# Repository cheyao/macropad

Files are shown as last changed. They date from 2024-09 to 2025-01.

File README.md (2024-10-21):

# Macropad
Hello! This is my first time designing a PCB and a CAD.

<p align="middle">
    
    
    
</p>

Designed using:

- KiCad - Made a ton of revisions
- OpenSCAD then FreeCAD (Fusion 360 doesn't work on my mac lol) Got like 400 constraints in my freecad project
- Python firmware

## Notes
Making the pad was fun ^.^ but I was just too paranoid that something would go wrong and made 15+ revisions lol. Ended up learning how to use OpenSCAD and FreeCAD.

## BOM
- 1 SEEEDUINO XIAO RP2040
- 16x [Kailh Choc V2 switches](https://www.kailh.net/products/kailh-choc-v2-low-profile-switch-set)
- 16x 1N4148 diodes
- 1x SSD1306 128x64O LED (5V VCC, 3.3V logic, I2C)
- 4x [SK6812-MINI-E LED](https://www.adafruit.com/product/4960)
- 2x 4.7k resistor
- 4x 0.1 uF capacitor (code 104, not obligatory but best have)
- 1x 1 uF capacitor (105 not obligatory)
- 4x same screws as orpheuspad and corresponding nuts
- 1kg of 99.99% gold please UwU

Interactive bom at `PCB/production/ibom.html`

## File list:

```
.
├── CAD                                         # 3D Files
│   ├── case.FCStd                              # Case FreeCAD design file
│   └── case
│       └── case.stl                            # The stl for the case
├── PCB
│   ├── macropad.step                           # 3D Model of the board
│   ├── production                              # The output directory for production (Just send this folder to JLCPCB)
│   │   ├── Cyao_macropad_v7.6.zip              # Final gerbers
│   │   ├── *.{csv,ipc}                         # Misc files for JLCPCB
│   │   └── ibom.html                           # Interactive bom for PCBAlex <3
│   └── third_party                             # 3rd party libraries
│       ├── Kalih                               # The keys
│       ├── OPL_Kicad_Library                   # Seed footprint
│       ├── KiCad-SSD1306-128x64-master         # LCD
│       └── Seeeduino-xiao-rp2040-KiCAD-Library # Seed schema
└── firmware                                    # Directory of my own firmware
    ├── adafruit-circuitpython-seeeduino_xiao_rp2040-en_US-9.1.4.uf2 # Circuitpython firmware
    ├── main.py                                 # Main firmware
    ├── boot.py                                 # Boot options (empty)
    └── kmk                                     # kmk firmware
```

NOTE: I will need a 0.96” SSD1306 OLED screen that accepts 5V with 3.3V logic

The resistors are allso probably optional - but suggested by reddit

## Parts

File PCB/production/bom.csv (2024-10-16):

Designator | Footprint | Quantity | Value | LCSC Part #
BRD1 | 128x64OLED | 1 | SSD1306
C1, C3, C4, C5 | C_Disc_D3.0mm_W1.6mm_P2.50mm | 4 | 0.1uF
C2 | C_Disc_D3.0mm_W1.6mm_P2.50mm | 1 | 1uF
D1, D10, D11, D12, D13, D14, D15, D16, D2, D3, D4, D5, D6, D7, D8, D9 | D_DO-35_SOD27_P7.62mm_Horizontal | 16 | Didode 1N4148
D17, D18, D21, D22 | SK6812MINI-E | 4 | SK6812MINI
R1, R2 | R_Axial_DIN0204_L3.6mm_D1.6mm_P7.62mm_Horizontal | 2 | 4.7k
SW1, SW10, SW11, SW12, SW13, SW14, SW15, SW16, SW2, SW3, SW4, SW5, SW6, SW7, SW8, SW9 | SW_Kailh_Choc_V2_1.00u | 16 | Kailh Choc V2
U2 | XIAO-Generic-Hybrid-14P-2.54-21X17.8MM | 1 | SEEEDUINO XIAO RP2040

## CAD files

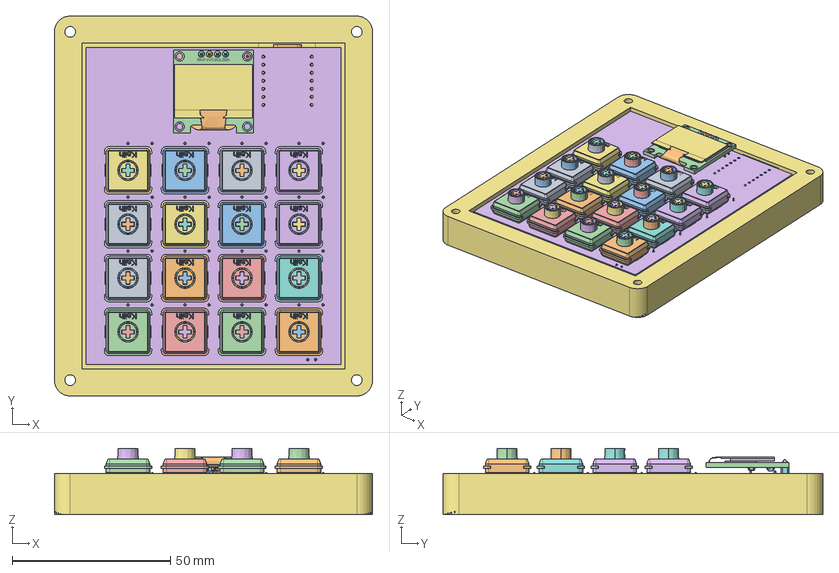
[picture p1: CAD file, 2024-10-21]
CAD/case.FCStd
100.5 x 120.0 x 21.0 mm
Kailh_PG1368
Kailh_PG1369
Kailh_PG1370
Kailh_PG1372
Kailh_PG1373
Kailh_PG1374
Kailh_PG1376
Kailh_PG1377
Kailh_PG1378
Kailh_PG1380
Kailh_PG1381
Kailh_PG1382
Kailh_PG1384
Kailh_PG1385
Kailh_PG1386
Kailh_PG1388
Kailh_PG1389
Kailh_PG1390
Kailh_PG1392
Kailh_PG1393
Kailh_PG1394
Kailh_PG1396
Kailh_PG1397
Kailh_PG1398
Kailh_PG1400
Kailh_PG1401
Kailh_PG1402
SSD1306_OLED_Display(128x64) v024
SSD1306_OLED_Display(128x64) v025
SSD1306_OLED_Display(128x64) v026
SSD1306_OLED_Display(128x64) v027
SSD1306_OLED_Display(128x64) v028
SSD1306_OLED_Display(128x64) v029
SSD1306_OLED_Display(128x64) v030
SSD1306_OLED_Display(128x64) v031
SSD1306_OLED_Display(128x64) v032
SSD1306_OLED_Display(128x64) v033
SSD1306_OLED_Display(128x64) v034
SSD1306_OLED_Display(128x64) v035
SSD1306_OLED_Display(128x64) v036
SSD1306_OLED_Display(128x64) v037
SSD1306_OLED_Display(128x64) v038
SSD1306_OLED_Display(128x64) v039
SSD1306_OLED_Display(128x64) v040
SSD1306_OLED_Display(128x64) v041
SSD1306_OLED_Display(128x64) v042
SSD1306_OLED_Display(128x64) v043
SSD1306_OLED_Display(128x64) v044
SSD1306_OLED_Display(128x64) v045
SSD1306_OLED_Display(128x64) v046
SSD1306_OLED_Display(128x64) v047
SSD1306_OLED_Display(128x64) v048
SSD1306_OLED_Display(128x64) v049
SSD1306_OLED_Display(128x64) v050
SSD1306_OLED_Display(128x64) v051
SSD1306_OLED_Display(128x64) v052
SSD1306_OLED_Display(128x64) v053
SSD1306_OLED_Display(128x64) v054
SSD1306_OLED_Display(128x64) v055
SSD1306_OLED_Display(128x64) v056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

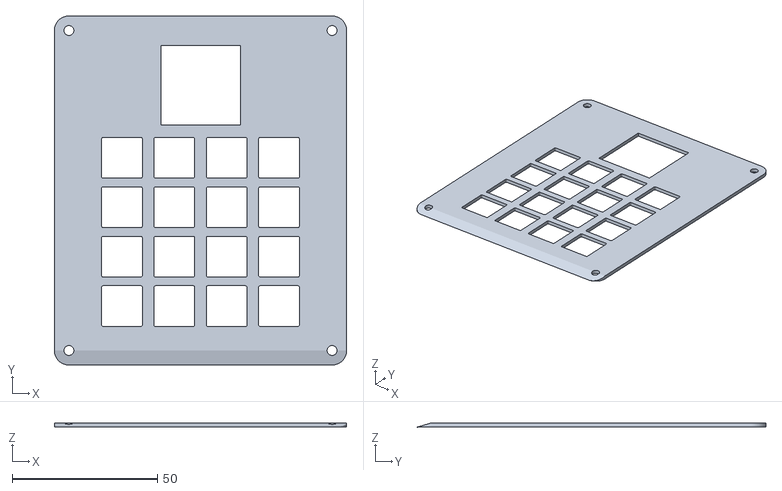
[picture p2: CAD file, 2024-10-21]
CAD/case/top.stl
100.5 x 120.0 x 1.50

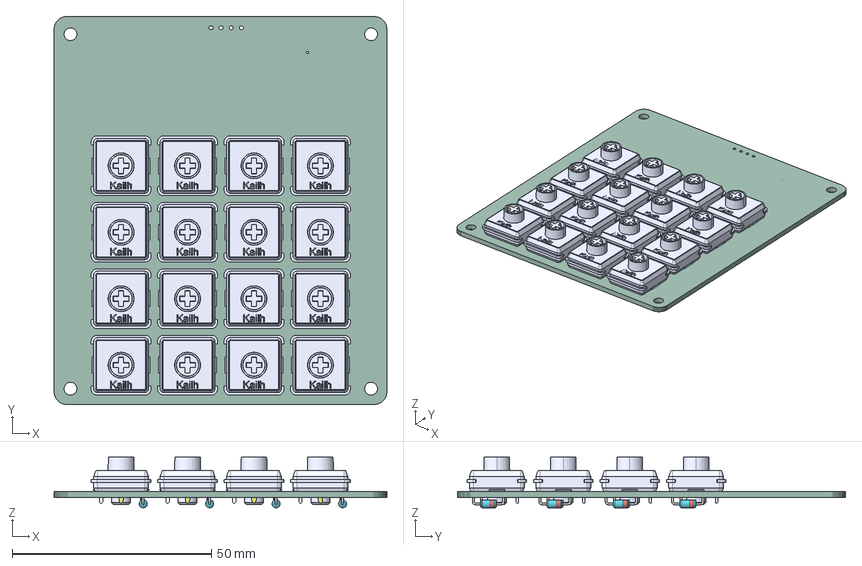
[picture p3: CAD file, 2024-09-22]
PCB/macropad.step
83.5 x 97.3 x 12.7 mm
Kailh_PG1352 x 16
D_DO-35_SOD27_P7.62mm_Horizontal x 16
macropad PCB

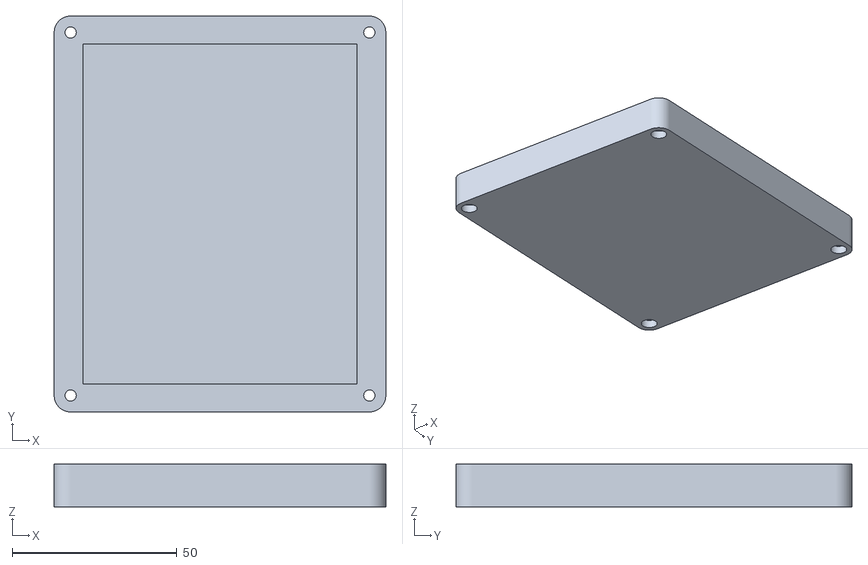
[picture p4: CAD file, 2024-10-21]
CAD/case/case.stl
100.5 x 120.0 x 13.0

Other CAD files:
CAD/case.stl

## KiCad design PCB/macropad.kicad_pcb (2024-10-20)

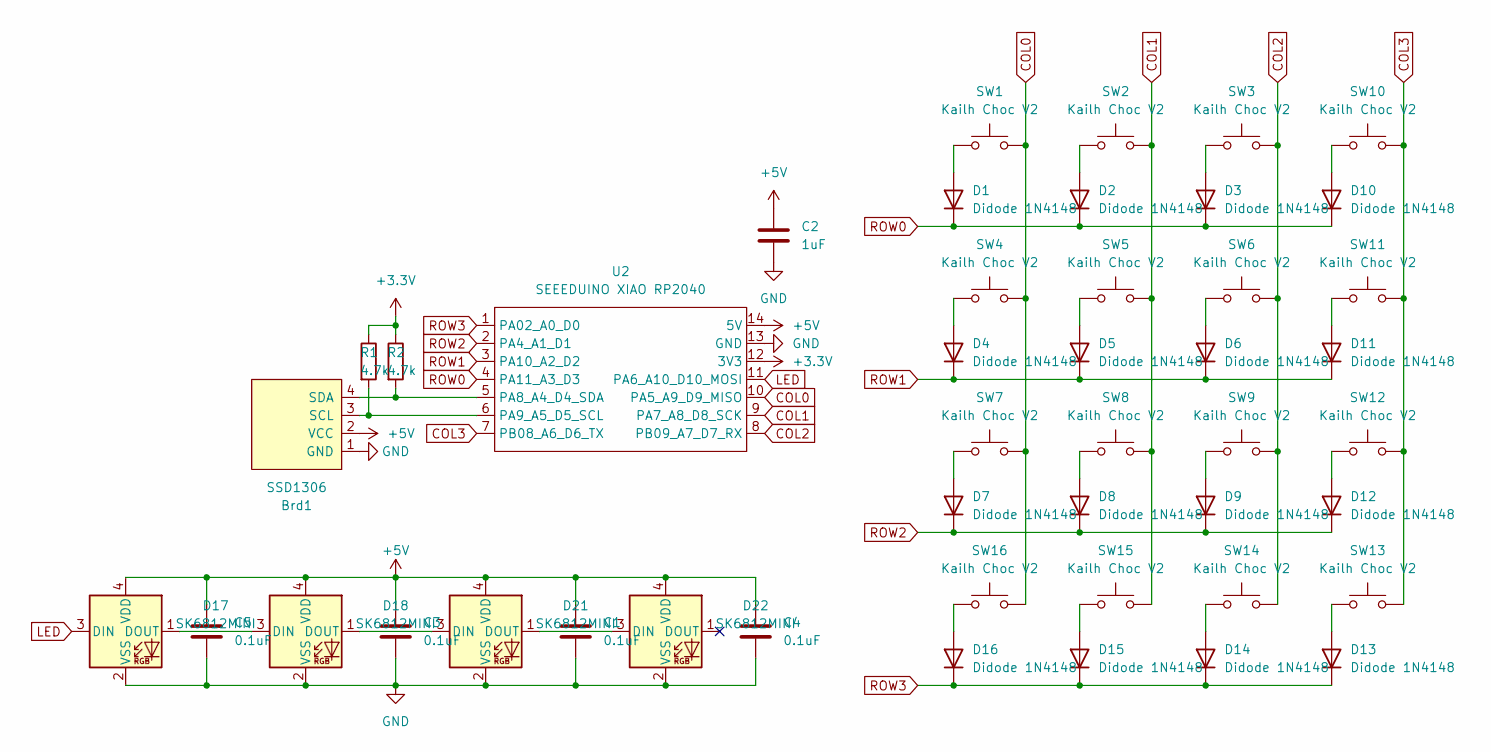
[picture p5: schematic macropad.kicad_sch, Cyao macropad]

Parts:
Brd1: SSD1306; 128x64OLED
C1, C3, C4, C5: 0.1uF; C_Disc_D3.0mm_W1.6mm_P2.50mm
C2: 1uF; C_Disc_D3.0mm_W1.6mm_P2.50mm
D1, D2, D3, D4, D5, D6, D7, D8, D9, D10, D11, D12, D13, D14, D15, D16: Didode 1N4148; D_DO-35_SOD27_P7.62mm_Horizontal
D17, D18, D21, D22: SK6812MINI; SK6812MINI-E
R1, R2: 4.7k; R_Axial_DIN0204_L3.6mm_D1.6mm_P7.62mm_Horizontal
SW1, SW2, SW3, SW4, SW5, SW6, SW7, SW8, SW9, SW10, SW11, SW12, SW13, SW14, SW15, SW16: Kailh Choc V2; SW_Kailh_Choc_V2_1.00u
U2: SEEEDUINO XIAO RP2040; XIAO-Generic-Hybrid-14P-2.54-21X17.8MM

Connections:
+3.3V: R1.1, R2.1, U2.12 (3V3)
+5V: Brd1.2 (VCC), C1.1, C2.1, C3.1, C4.1, C5.1, D17.4 (VDD), D18.4 (VDD), D21.4 (VDD), D22.4 (VDD), U2.14 (5V)
COL0: SW1.2, SW4.2, SW7.2, SW16.2, U2.10 (PA5_A9_D9_MISO)
COL1: SW2.2, SW5.2, SW8.2, SW15.2, U2.9 (PA7_A8_D8_SCK)
COL2: SW3.2, SW6.2, SW9.2, SW14.2, U2.8 (PB09_A7_D7_RX)
COL3: SW10.2, SW11.2, SW12.2, SW13.2, U2.7 (PB08_A6_D6_TX)
GND: Brd1.1 (GND), C1.2, C2.2, C3.2, C4.2, C5.2, D17.2 (VSS), D18.2 (VSS), D21.2 (VSS), D22.2 (VSS), U2.13 (GND)
LED: D17.3 (DIN), U2.11 (PA6_A10_D10_MOSI)
unnamed: Brd1.3 (SCL), R1.2, U2.6 (PA9_A5_D5_SCL)
unnamed: Brd1.4 (SDA), R2.2, U2.5 (PA8_A4_D4_SDA)
unnamed: D1.2 (A), SW1.1
unnamed: D2.2 (A), SW2.1
unnamed: D3.2 (A), SW3.1
unnamed: D4.2 (A), SW4.1
unnamed: D5.2 (A), SW5.1
unnamed: D6.2 (A), SW6.1
unnamed: D7.2 (A), SW7.1
unnamed: D8.2 (A), SW8.1
unnamed: D9.2 (A), SW9.1
unnamed: D10.2 (A), SW10.1
unnamed: D11.2 (A), SW11.1
unnamed: D12.2 (A), SW12.1
unnamed: D13.2 (A), SW13.1
unnamed: D14.2 (A), SW14.1
unnamed: D15.2 (A), SW15.1
unnamed: D16.2 (A), SW16.1
unnamed: D17.1 (DOUT), D18.3 (DIN)
unnamed: D18.1 (DOUT), D21.3 (DIN)
unnamed: D21.1 (DOUT), D22.3 (DIN)
ROW0: D1.1 (K), D2.1 (K), D3.1 (K), D10.1 (K), U2.4 (PA11_A3_D3)
ROW1: D4.1 (K), D5.1 (K), D6.1 (K), D11.1 (K), U2.3 (PA10_A2_D2)
ROW2: D7.1 (K), D8.1 (K), D9.1 (K), D12.1 (K), U2.2 (PA4_A1_D1)
ROW3: D13.1 (K), D14.1 (K), D15.1 (K), D16.1 (K), U2.1 (PA02_A0_D0)

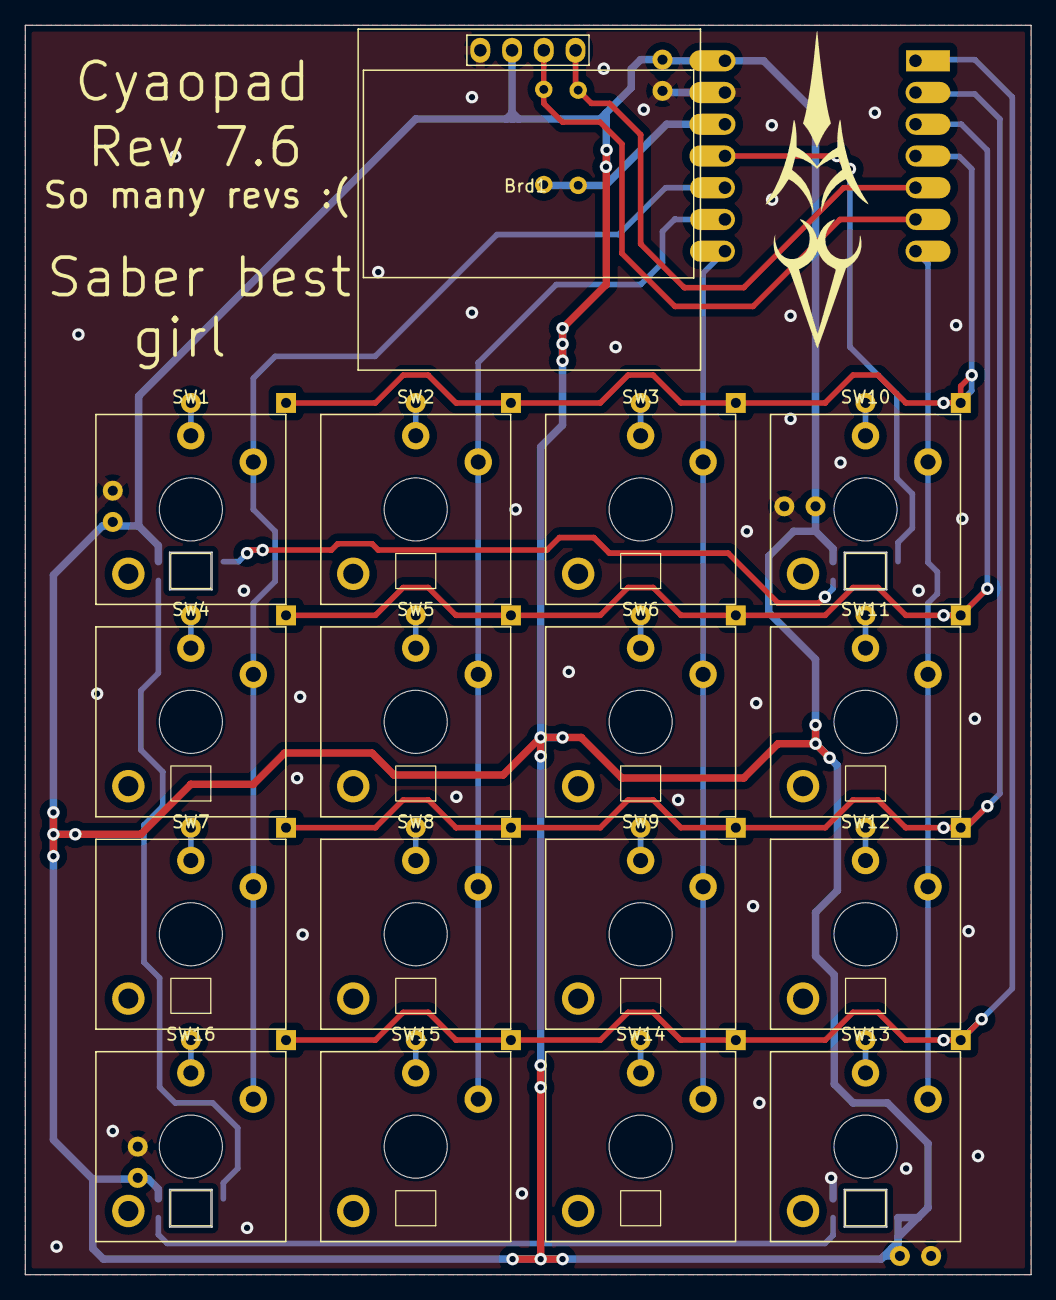
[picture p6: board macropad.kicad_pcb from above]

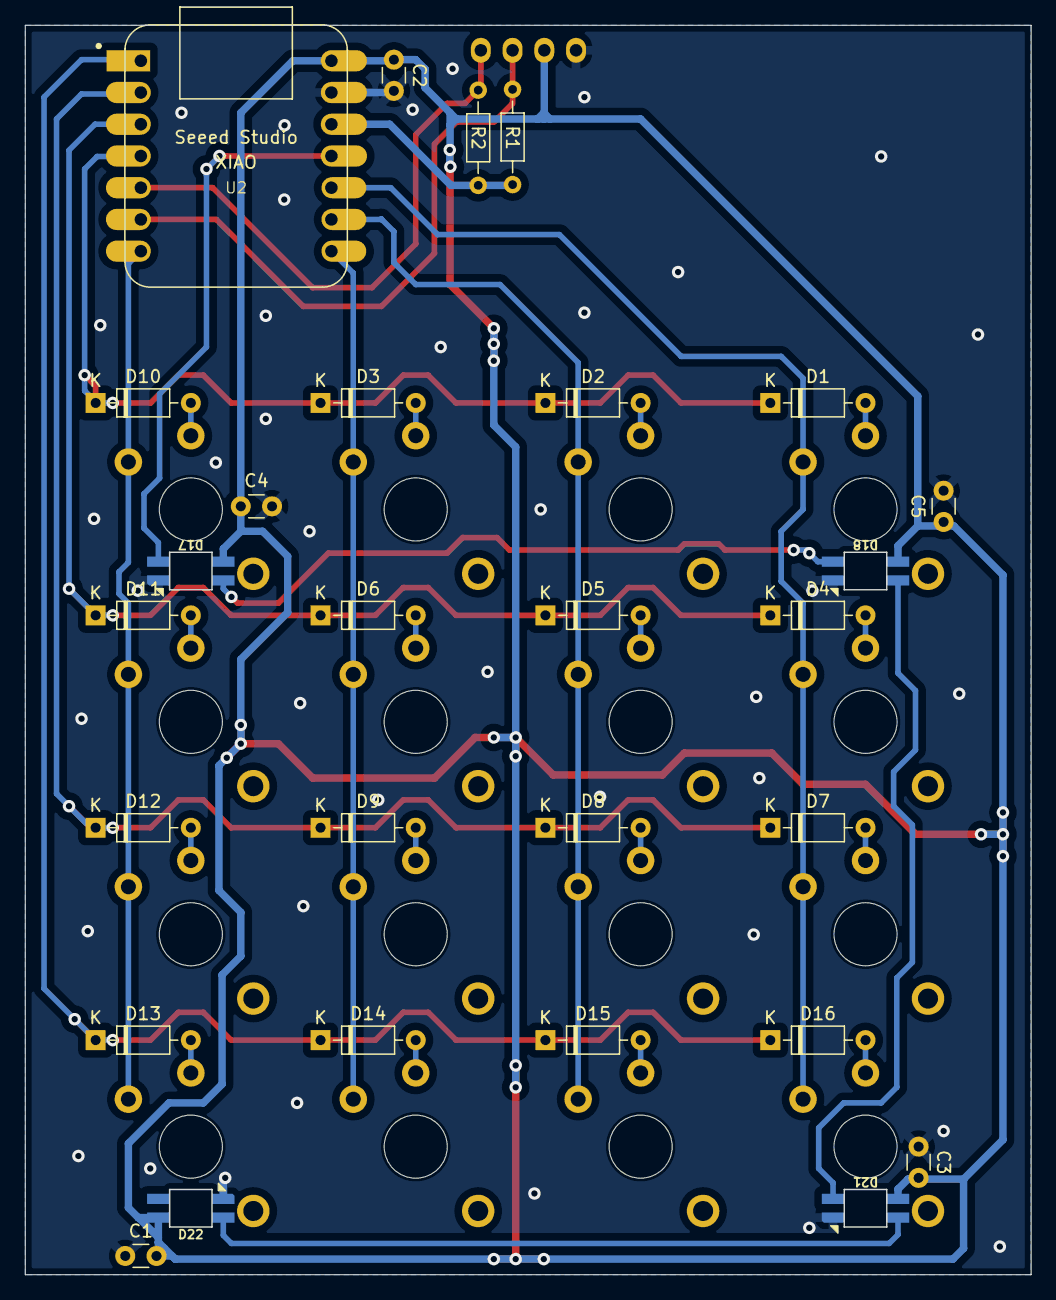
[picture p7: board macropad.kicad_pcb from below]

Board: 2 copper layers, 80.5 x 100.0 mm, 45 parts (28 on the bottom side), 33 nets.

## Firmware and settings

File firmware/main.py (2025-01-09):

# Cyao macropad firmware
# Rev 1.1
# Copyright 2024
# Licensed under zlib license
import board
import busio
import time
import board
from rainbowio import colorwheel

from kmk.kmk_keyboard import KMKKeyboard
from kmk.keys import KC
from kmk.scanners import DiodeOrientation
from kmk.modules.macros import Macros
from kmk.extensions.display import Display, TextEntry, ImageEntry
from kmk.extensions.display.ssd1306 import SSD1306
from kmk.extensions.RGB import RGB
from kmk.extensions.rgb import AnimationModes

COL0 = board.D9;
COL1 = board.D8;
COL2 = board.D7;
COL3 = board.D6;
ROW0 = board.D3;
ROW1 = board.D2;
ROW2 = board.D1;
ROW3 = board.D0;

LED_PIN = board.D10;

bus = busio.I2C(board.SCL, board.SDA);

driver = SSD1306(i2c=bus, device_address=0x3C);

display = Display(
    display=driver,
    width=128,
    height=64,
    dim_time=10,
    dim_target=0.2,
    off_time=1200,
    brightness=0.7
);

display.entries = [
    ImageEntry(image="pic.bmp", x=0, y=0),
];

keyboard = KMKKeyboard();

macros = Macros();
keyboard.modules.append(macros);
keyboard.extensions.append(display);

keyboard.col_pins = (COL0, COL1, COL2, COL3);
keyboard.row_pins = (ROW0, ROW1, ROW2, ROW3);
keyboard.diode_orientation = DiodeOrientation.COL2ROW;

rgb = RGB(pixel_pin=board.D10, num_pixels=4, animation_speed=1, animation_mode=AnimationModes.SWIRL)
keyboard.extensions.append(rgb)

from kmk.modules.macros import Press, Release, Tap, Delay
from kmk.modules.mouse_keys import MouseKeys
keyboard.modules.append(MouseKeys())

A = KC.MACRO(
    Press(KC.LCMD),
    Tap(KC.T),
    Release(KC.LCMD)
);
B = KC.MACRO(
    Press(KC.LALT),
    Tap(KC.T),
    Release(KC.LALT)
);
C = KC.MACRO(
    Press(KC.LALT),
    Tap(KC.W),
    Release(KC.LALT)
);
D = KC.MACRO(
    Press(KC.LCMD),
    Tap(KC.Q),
    Release(KC.LCMD)
);

E = KC.MS_LT;
F = KC.MS_DN;
G = KC.MS_UP;
H = KC.MS_RT;

I = KC.MW_DN;
J = KC.MW_UP;
K = KC.MACRO(
    Press(KC.LCMD),
    Press(KC.LSFT),
    Tap(KC.F),
    Release(KC.LCMD),
    Release(KC.LSFT),
);
L = KC.LALT;

M = KC.MB_LMB;
N = KC.MB_RMB;
O = KC.MACRO(
    Press(KC.LCMD),
    Tap(KC.LEFT),
    Release(KC.LCMD)
);
P = KC.MACRO(
    Press(KC.LCMD),
    Tap(KC.RIGHT),
    Release(KC.LCMD)
);

keyboard.keymap = [
    [A, B, C, D,
     E, F, G, H,
     I, J, K, L,
     M, N, O, P],
];

if __name__ == '__main__':
    keyboard.go();

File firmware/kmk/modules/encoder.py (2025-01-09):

# See docs/encoder.md for how to use

import busio
import digitalio
from supervisor import ticks_ms

from kmk.modules import Module
from kmk.utils import Debug

debug = Debug(__name__)

# NB : not using rotaryio as it requires the pins to be consecutive


class BaseEncoder:

    VELOCITY_MODE = True

    def __init__(self, is_inverted=False, divisor=4):

        self.is_inverted = is_inverted
        self.divisor = divisor

        self._state = None
        self._start_state = None
        self._direction = None
        self._pos = 0
        self._button_state = True
        self._button_held = None
        self._velocity = 0

        self._movement = 0
        self._timestamp = ticks_ms()

        # callback functions on events. Need to be defined externally
        self.on_move_do = None
        self.on_button_do = None

    def get_state(self):
        return {
            'direction': self.is_inverted and -self._direction or self._direction,
            'position': self.is_inverted and -self._pos or self._pos,
            'is_pressed': not self._button_state,
            'velocity': self._velocity,
        }

        # Called in a loop to refresh encoder state

    def update_state(self):
        # Rotation events
        new_state = (self.pin_a.get_value(), self.pin_b.get_value())

        if new_state != self._state:
            # encoder moved
            self._movement += 1
            # false / false and true / true are common half steps
            # looking on the step just before helps determining
            # the direction
            if new_state[0] == new_state[1] and self._state[0] != self._state[1]:
                if new_state[1] == self._state[0]:
                    self._direction = 1
                else:
                    self._direction = -1

            # when the encoder settles on a position (every 2 steps)
            if new_state[0] == new_state[1]:
                # an encoder returned to the previous
                # position halfway, cancel rotation
                if (
                    self._start_state[0] == new_state[0]
                    and self._start_state[1] == new_state[1]
                    and self._movement <= 2
                ):
                    self._movement = 0
                    self._direction = 0

                # when the encoder made a full loop according to its divisor
                elif self._movement >= self.divisor - 1:
                    # 1 full step is 4 movements (2 for high-resolution encoder),
                    # however, when rotated quickly, some steps may be missed.
                    # This makes it behave more naturally
                    real_movement = self._movement // self.divisor
                    self._pos += self._direction * real_movement
                    if self.on_move_do is not None:
                        for i in range(real_movement):
                            self.on_move_do(self.get_state())

                    # Rotation finished, reset to identify new movement
                    self._movement = 0
                    self._direction = 0
                    self._start_state = new_state

            self._state = new_state

        # Velocity
        self.velocity_event()

        # Button event
        self.button_event()

    def velocity_event(self):
        if self.VELOCITY_MODE:
            new_timestamp = ticks_ms()
            self._velocity = new_timestamp - self._timestamp
            self._timestamp = new_timestamp

    def button_event(self):
        raise NotImplementedError('subclasses must override button_event()!')

    # return knob velocity as milliseconds between position changes (detents)
    # for backwards compatibility
    def vel_report(self):
        return self._velocity


class GPIOEncoder(BaseEncoder):
    def __init__(
        self,
        pin_a,
        pin_b,
        pin_button=None,
        is_inverted=False,
        divisor=None,
        button_pull=digitalio.Pull.UP,
    ):
        super().__init__(is_inverted)

        # Divisor can be 4 or 2 depending on whether the detent
        # on the encoder is defined by 2 or 4 pulses
        self.divisor = divisor

        self.pin_a = EncoderPin(pin_a)
        self.pin_b = EncoderPin(pin_b)
        if pin_button:
            self.pin_button = EncoderPin(pin_button, button_type=True, pull=button_pull)
        else:
            self.pin_button = None

        self._state = (self.pin_a.get_value(), self.pin_b.get_value())
        self._start_state = self._state

    def button_event(self):
        if self.pin_button:
            new_button_state = self.pin_button.get_value()
            if new_button_state != self._button_state:
                self._button_state = new_button_state
                if self.on_button_do is not None:
                    self.on_button_do(self.get_state())


class EncoderPin:
    def __init__(self, pin, button_type=False, pull=digitalio.Pull.UP):
        self.pin = pin
        self.button_type = button_type
        self.pull = pull
        self.prepare_pin()

    def prepare_pin(self):
        if self.pin is not None:
            if isinstance(self.pin, digitalio.DigitalInOut):
                self.io = self.pin
            else:
                self.io = digitalio.DigitalInOut(self.pin)
            self.io.direction = digitalio.Direction.INPUT
            self.io.pull = self.pull
        else:
            self.io = None

    def get_value(self):
        io = self.io
        result = io.value
        if digitalio.Pull.UP != io.pull:
            result = not result
        return result
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

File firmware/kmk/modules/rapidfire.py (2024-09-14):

from micropython import const

from random import randint

from kmk.keys import Key, make_argumented_key
from kmk.modules import Module
from kmk.utils import Debug

debug = Debug(__name__)

_INACTIVE = const(0)
_HOLD = const(1)
_ACTIVE = const(2)


class RapidFireKey(Key):
    def __init__(
        self,
        key,
        interval=100,
        timeout=200,
        enable_interval_randomization=False,
        randomization_magnitude=15,
        toggle=False,
        **kwargs,
    ):
        super().__init__(**kwargs)
        self.key = key
        self.interval = interval
        self.timeout = timeout
        self.enable_interval_randomization = enable_interval_randomization
        self.randomization_magnitude = randomization_magnitude
        self.toggle = toggle
        self._state = _INACTIVE
        self._timeout = None


class RapidFire(Module):
    def __init__(self):
        make_argumented_key(
            names=('RF',),
            constructor=RapidFireKey,
            on_press=self._rf_pressed,
            on_release=self._rf_released,
        )

    def _on_timer_timeout(self, key, keyboard):
        if key._state == _HOLD:
            key._state = _ACTIVE
            keyboard.remove_key(key.key)
            key._timeout = keyboard.set_timeout(
                1, lambda: self._on_timer_timeout(key, keyboard)
            )
            return

        keyboard.add_key(key.key)
        keyboard.set_timeout(1, lambda: keyboard.remove_key(key.key))

        interval = key.interval
        if key.enable_interval_randomization:
            interval += randint(
                -key.randomization_magnitude, key.randomization_magnitude
            )
        key._timeout = keyboard.set_timeout(
            interval, lambda: self._on_timer_timeout(key, keyboard)
        )

        if debug.enabled:
            debug(key.key, ' @', interval, 'ms')

    def _rf_pressed(self, key, keyboard, *args, **kwargs):
        if key._state == _ACTIVE:
            self._deactivate_key(key, keyboard)
            return

        keyboard.add_key(key.key)
        key._state = _HOLD
        key._timeout = keyboard.set_timeout(
            key.timeout, lambda: self._on_timer_timeout(key, keyboard)
        )

    def _rf_released(self, key, keyboard, *args, **kwargs):
        if key._state == _ACTIVE:
            if key.toggle:
                return
            key._state = _INACTIVE
        elif key._state == _INACTIVE:
            return
        else:
            keyboard.remove_key(key.key)

        self._deactivate_key(key, keyboard)

    def _deactivate_key(self, key, keyboard):
        keyboard.cancel_timeout(key._timeout)
        key._state = _INACTIVE
        key._timeout = None

    def during_bootup(self, keyboard):
        return

    def before_matrix_scan(self, keyboard):
        return

    def before_hid_send(self, keyboard):
        return

    def after_hid_send(self, keyboard):
        return

    def on_powersave_enable(self, keyboard):
        return

    def on_powersave_disable(self, keyboard):
        return

    def after_matrix_scan(self, keyboard):
        return

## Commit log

2024-09-12 Save, half-finished schematic, start of PCB
    [macropad.kicad_pcb, macropad.kicad_sch]
2024-09-13 Finish first state of PCB
    [macropad.kicad_pcb, macropad.kicad_sch]
2024-09-14 Improved PCB
    [macropad.kicad_pcb]
2024-09-14 Start of firmware
    [case.scad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]
2024-09-14 Start of case
    [case.scad, cyl_head_bolt-drawAllScript.scad, cyl_head_bolt.scad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]
2024-09-14 Mis of case
    [case.scad]
2024-09-14 Finish Case
    [case.scad, case.stl, cover.scad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]
2024-09-15 Finish macropad
    [case.scad, case.stl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]
2024-09-15 Fix stuff
    [case.scad, case.stl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]
2024-09-21 Add step & stl for PCB
    [macropad.step, macropad.stl]
2024-09-22 Add 3D models
    [macropad.kicad_pcb]
2024-09-22 Increase cover keypad hole size
    [cover.scad, cover.stl]
2024-09-22 Add file names, clean up designators & Improve output
    [macropad-B_Cu.gbl, macropad-B_Mask.gbs, macropad-B_Paste.gbp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]
2024-09-22 Fix .gitignore
    [bom.csv, designators.csv, positions.csv]
2024-09-22 Fix pads
    [bom.csv, designators.csv, macropad.kicad_pcb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]
2024-09-22 Added 3D model for xiao
    [macropad.kicad_pcb, macropad.kicad_sch]
2024-09-22 Fix CAD usb hole alignment
    [case.scad, case.stl]
2024-09-22 Add pullup resistors for I2C
    [bom.csv, designators.csv, macropad.kicad_pcb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]
2024-09-23 Moved diodes
    [designators.csv, macropad.kicad_pcb, positions.csv]
2024-09-23 Add plate and use insert for case
    [case.scad, cover.scad, cyl_head_bolt-drawAllScript.scad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]
2024-09-24 Change side of tracks connecting to keys
    [macropad.kicad_pcb]
2024-09-25 Misc improvements
    [macropad.kicad_pcb, macropad.kicad_sch]
2024-09-26 Use thru-hole xiao
    [bom.csv, macropad.kicad_pcb, macropad.kicad_sch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]
2024-10-03 Redisigned PCB
    [macropad.kicad_pcb, macropad.kicad_sch]
2024-10-05 Revamped switch footprints and routing
    [bom.csv, designators.csv, macropad.kicad_pcb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]
2024-10-06 Add LEDs to PCB
    [bom.csv, designators.csv, macropad.kicad_pcb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]
2024-10-06 Add case
    [case.FCStd, case.scad, case.stl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]
2024-10-06 Finish firmware + misc updates
    [macropad.kicad_pcb, macropad.kicad_sch]
2024-10-07 Add BOM in readme
2024-10-08 Add decoupling capacitors & verified footprints
    [bom.csv, designators.csv, macropad.kicad_pcb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]
2024-10-08 Revamp switch margins
    [macropad.kicad_pcb, macropad.kicad_sch]
2024-10-08 Adapt case to new switch margins
    [case.FCStd, case.stl]
2024-10-09 Added backlights
    [bom.csv, case.FCStd, case.stl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]
2024-10-09 Add silkscreens and misc improvements
    [bom.csv, designators.csv, macropad.kicad_pcb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]
2024-10-10 Firmware path + clean up tracks
    [macropad.kicad_pcb]
2024-10-16 Change capacitor values and positions
    [bom.csv, designators.csv, macropad.kicad_pcb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]
2024-10-17 Follow best practices and use stiching vias
    [macropad.kicad_pcb]
2024-10-17 Add slope to case
    [case.FCStd, case.stl]
2024-10-20 Final revision
    [case.FCStd, macropad.kicad_pcb, plate.dxf]
2024-10-21 Sync with the hackpad
    [case.FCStd, case.stl, top.stl]
2025-01-09 Fix firmware
    [macropad-B_Courtyard.gbr, macropad-B_Cu.gbl, macropad-B_Fab.gbr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]
